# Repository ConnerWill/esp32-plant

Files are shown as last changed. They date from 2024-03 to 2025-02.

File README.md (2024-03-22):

# ESP32 Plant Monitoring / Watering System

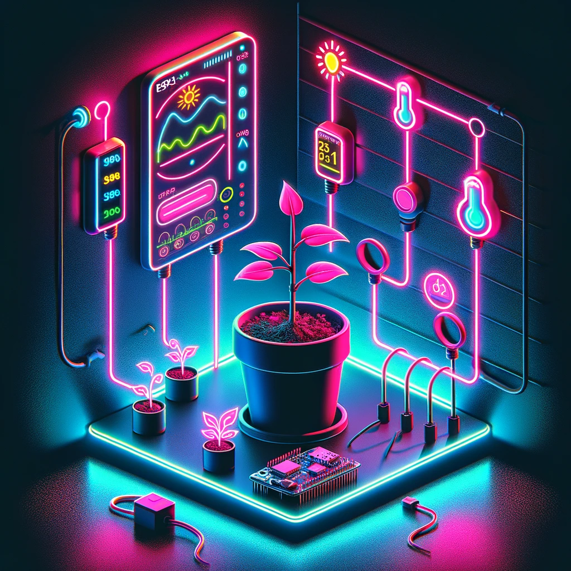
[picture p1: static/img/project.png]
ESP32 Plant Monitoring Project Image


---

# Overview

This project implements a monitoring system using an ESP32 microcontroller to measure and display temperature, humidity, and CO2 levels in real-time.

This is designed to be used to monitor the environment when growing plants

---

# Shopping List

Here is a list of parts used in this project

> *Amazon links are non-affiliate*

| NAME | PRICE | COUNT | DESCRIPTION | LINK | NOTE |
|---|---|---|---|---|---|
| ESP32 | $5 | 1 | Microcontroller | https://www.amazon.com/ESP-WROOM-31-Development-Microcontroller-Integrated-Compatible/dp/B08D5ZD528 | |
| DHT22 | $7 | 1 | Temp/Humidity Sensor | https://www.amazon.com/gp/product/B0795F19W6 | |
| MQ-135 | $3 | 1 | CO2 Sensor | https://www.amazon.com/Ximimark-Quality-Hazardous-Detection-Arduino/dp/B07L73VTTY | |
| 1K Ω Resistor  | $0.25 | 1 | 1K Ohm Resistor | https://www.amazon.com/California-JOS-Carbon-Resistor-Tolerance/dp/B0BR66ZN6B | MQ-135 analog pin |
| 10K Ω Resistor | $0.25 | 0/1 | 10K Ohm Resistor | https://www.amazon.com/California-JOS-Carbon-Resistor-Tolerance/dp/B0BR67DJHM | Most DHT22 sensor modules have a built-in resistor |
| Wire/Breadboard| $1 | 1 | Jumper wire or breadboard | https://www.amazon.com/DEYUE-breadboard-Set-Prototype-Board/dp/B07LFD4LT6 | Optional depending on setup |

<!--
| TLC555         | $3    | 1     | Capacitive soil moisture sensor | https://www.amazon.com/dp/B0C5STDNSX                                                                |                                                    |
| SSD1306        | $6    | 1     | 0.96" 128x64 OLED         | https://www.amazon.com/HiLetgo-Serial-128X64-Display-Color/dp/B06XRBTBTB                            | Optional if you want a screen display              |
| ENS160       | $5    | 0/1   | CO2 Sensor           | https://www.amazon.com/HiLetgo-Dioxide-Temperature-Humidity-Monitoring/dp/B0CDWYFSGH                |
| SGP30        | $5    | 0/1   | CO2 Sensor           | https://www.makerfabs.com/sgp30-air-quality-sensor-breakout.html                                    |
-->

> *Lower prices can be found if you shop around*

---

# Setup

Once you have all the required parts in hand, you can start wiring

## Circuit Schematic

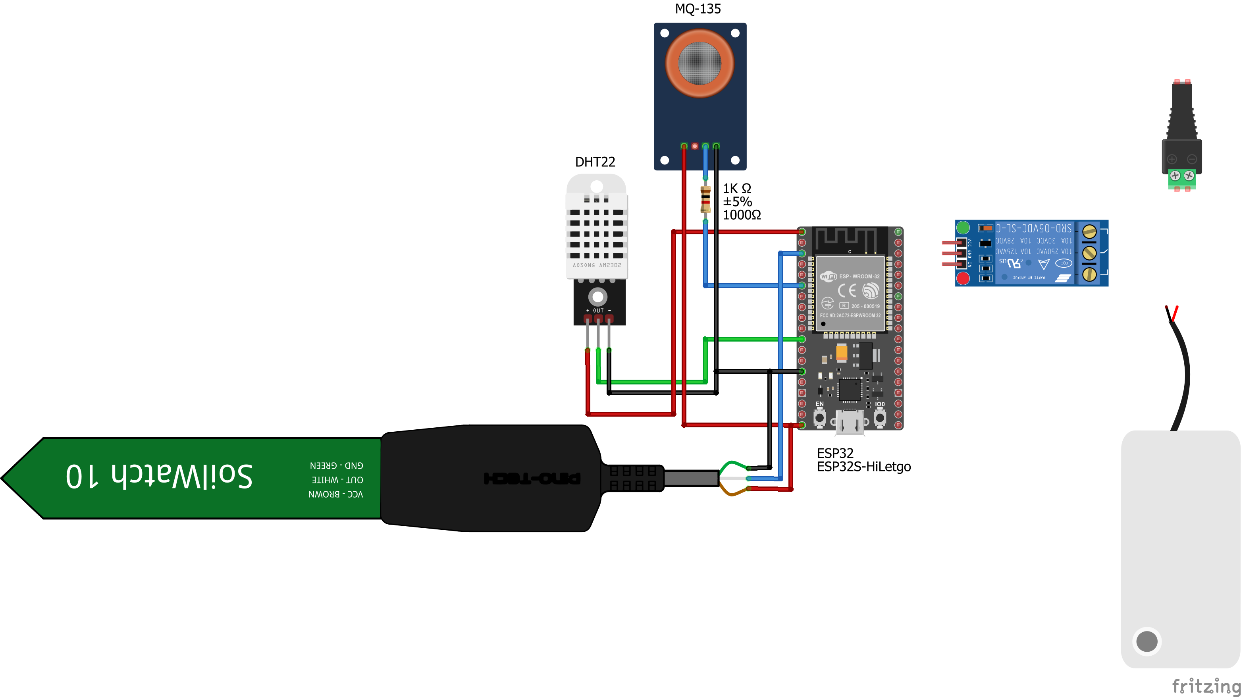
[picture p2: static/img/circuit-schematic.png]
ESP32 Plant Monitoring Circuit Schematic Image


| ESP32 Pin | Destination | Type | Power Requirements (Volts) | ESP32 VCC Pin | ESP32 GND Pin |
|---|---|---|---|---|---|
| 27 | DHT22 | Digital | 3-5 | 3.3V | GND |
| 35 | CO2 Sensor  | Analog  | 5 | 5V | GND |

> *Feel free to change the pins used on the ESP32, just note, if you change the pins, you will need to update the values in the code.*

## Configuration

You will need to define values to suite your needs. Variables are defined in [`./src/main/config.h`](/src/main/config.h)

### WiFI Configuration

Here is a list of WiFi variables that **must** be defined and their descriptions...

`WIFI_SSID`
: WiFi SSID (network/WiFi name)

`WIFI_PASSWORD`
: WiFi password

`WIFI_HOSTNAME`
: Hostname of ESP32 to set

### Other Configuration

Other variables in [`config.h`](/src/main/config.h) can be changed to suite your needs

## Uploading

I use Arduino IDE to upload the code to the board. I had to install additional drivers ***[(Download)](https://www.silabs.com/documents/public/software/CP210x_Universal_Windows_Driver.zip)*** to get connected to my board.

I installed the ESP32 boards and selected ESP32dev board.

---

# 3D Print

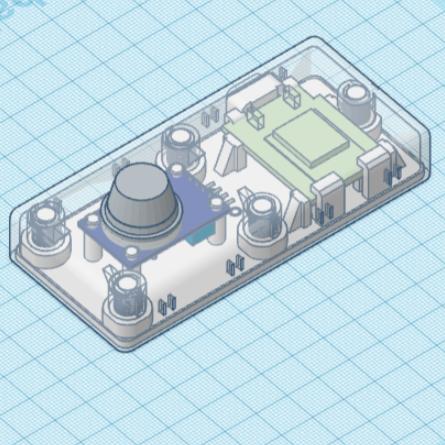
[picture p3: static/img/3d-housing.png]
ESP32 Plant Monitoring Housing Image


The housing to hold the ESP32 and sensors can be 3D printed.

The 3D model files are located under the [3D-models](/3D-models) directory.

## DHT22 Case

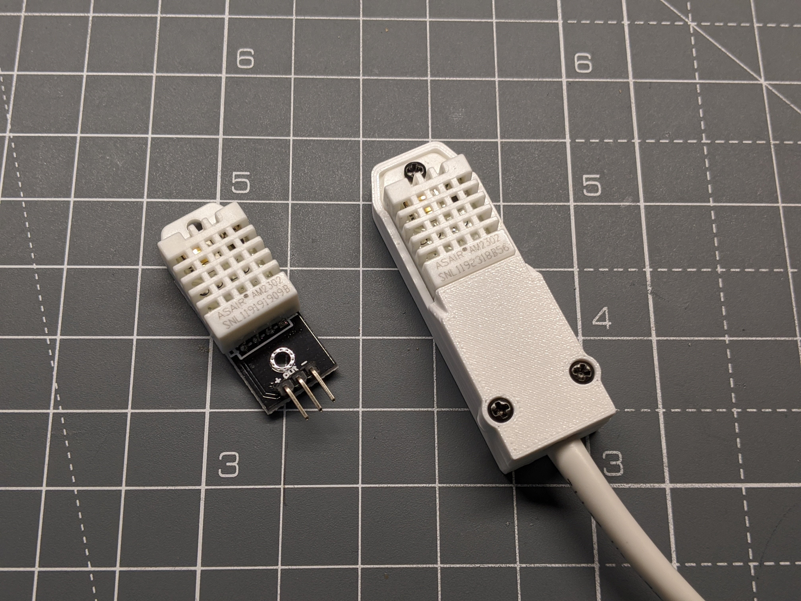
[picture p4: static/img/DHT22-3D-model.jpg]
DHT22 3D Printed Case


[Over-engineered DHT22 / AM2302 Board Case](https://www.thingiverse.com/thing:4521313)
: (Credit [SciMonster](https://www.thingiverse.com/SciMonster))

## MQ-135 Case

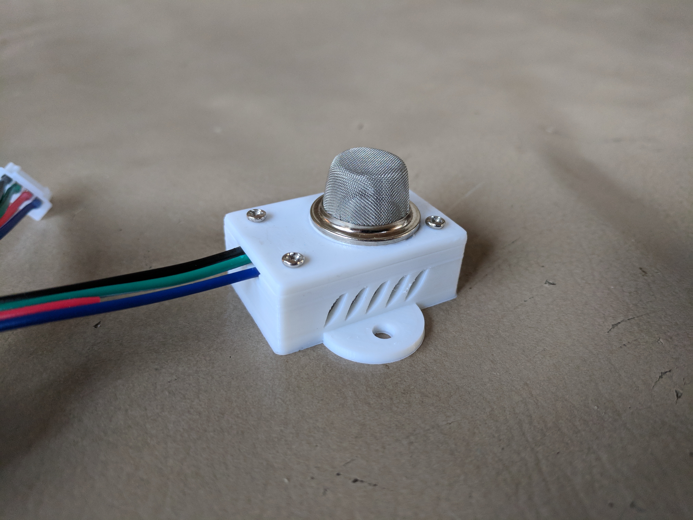
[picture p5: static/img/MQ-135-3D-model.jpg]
MQ-135 3D Printed Case


[MQ-2 Sensor Case](https://www.thingiverse.com/thing:2893581)
: (Credit [RJGII](https://www.thingiverse.com/RJGII))

---

# TODO

* Add wiring/setup instructions
* Add 3D models
* Replace images
* Improve code
* Add plotting

---

# Links

* https://microcontrollerslab.com/esp32-dht11-dht22-web-server
* https://blog.asksensors.com/air-quality-sensor-mq135-cloud-mqtt
* https://maker.pro/everything-esp/projects/how-to-control-a-relay-module-with-esp32
* https://www.thingiverse.com/thing:4521313
* https://www.thingiverse.com/thing:2893581

---

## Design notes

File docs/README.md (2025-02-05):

# ESP32 Plant Monitoring System

<div align="center">

ESP32 Plant Monitoring Project Image





</div>

---

## Table of Contents

<!--toc:start-->
- [ESP32 Plant Monitoring System](#esp32-plant-monitoring-system)
  - [Table of Contents](#table-of-contents)
  - [Overview](#overview)
  - [Shopping List](#shopping-list)
  - [Setup](#setup)
    - [Circuit Schematic](#circuit-schematic)
    - [ESP32 Pinout](#esp32-pinout)
      - [30 Pin](#30-pin)
      - [38 Pin](#38-pin)
    - [Configuration](#configuration)
      - [WiFI Configuration](#wifi-configuration)
      - [Other Configuration](#other-configuration)
    - [Libraries](#libraries)
      - [External Libraries](#external-libraries)
    - [Uploading](#uploading)
  - [Images](#images)
  - [3D Print](#3d-print)
  - [TODO](#todo)
  - [Links](#links)
<!--toc:end-->

---

## Overview

This project implements a monitoring system using an ESP32 microcontroller to
measure and display temperature, humidity, and CO2 levels in real-time.

This is designed to be used to monitor the environment when growing plants

---

## Shopping List

Here is a list of parts used in this project

> [!NOTE]
> *Amazon links are non-affiliate*

| NAME | PRICE | COUNT | DESCRIPTION | LINK | NOTE |
|---|---|---|---|---|---|
| ESP32 | $5 | 1 | Microcontroller | [Amazon](https://www.amazon.com/ESP-WROOM-31-Development-Microcontroller-Integrated-Compatible/dp/B08D5ZD528) | [USB-C ESP32 Amazon](https://www.amazon.com/dp/B0CR5Y2JVD) |
| DHT22 | $3 | 1 | Temp/Humidity Sensor | [Amazon](https://www.amazon.com/dp/B0CPHQC9SF) | |
| MQ-135 | $3 | 1 | CO2 Sensor | [Amazon](https://www.amazon.com/Ximimark-Quality-Hazardous-Detection-Arduino/dp/B07L73VTTY) | |
| OLED Display | $3 | 1 | 0.96" OLED Display 128x64 SSD1306 | [Amazon](https://www.amazon.com/Hosyond-Display-Self-Luminous-Compatible-Raspberry/dp/B09C5K91H7) | |
| Kasa Smart Plug  | $7.50 | 2 | TP-Link Kasa Smart Plug HS103 | [Amazon](https://www.amazon.com/dp/B07RCNB2L3) | Intake and exhaust fans smart plugs |
| Rocker Switch | $0.60 | 2 | Rocker Switch On/Off 2 Pin | [Amazon](https://www.amazon.com/dp/B0CVTRKJTV) | |
| 1K Ω Resistor | $0.25 | 1 | 1K Ohm Resistor | [Amazon](https://www.amazon.com/California-JOS-Carbon-Resistor-Tolerance/dp/B0BR66ZN6B) | MQ-135 analog pin |
| 10K Ω Resistor | $0.25 | 0/1/2 | 10K Ohm Resistor | [Amazon](https://www.amazon.com/California-JOS-Carbon-Resistor-Tolerance/dp/B0BR67DJHM) | Most DHT22 sensor modules have a built-in resistor |
| Wire/Breadboard  | $1 | 0/1 | Jumper wire or breadboard | [Amazon](https://www.amazon.com/DEYUE-breadboard-Set-Prototype-Board/dp/B07LFD4LT6) | Optional depending on setup |
| Breakout Board | $4 | 0/1 | ESP32 Breakout Board GPIO | [Amazon](https://www.amazon.com/dp/B0BNQ8V65G) | Optional depending on setup |
| Buck Converter | $1 | 0/1 | LM2596 DC-DC Buck Converter Step Down | [Amazon](https://www.amazon.com/dp/B07VVXF7YX) | Optional depending on setup |
| Barrel Jack | $1 | 0/1 | Female DC Barrel Jack Panel Adapter | [Amazon](https://www.amazon.com/Threaded-Adapter-Connector-Dustproof-lkelyonewy/dp/B091PS6XQ4) | Optional depending on setup |
| 1N5819 Diode | $0.1 | 0/1 | 1N5819 Schottky Diode | [Amazon](https://www.amazon.com/ALLECIN-1N5819-Schottky-Rectifier-Switching/dp/B0CKSHSWPS) | Optional depending on setup |
| 1000µF Capacitor | $0.4 | 0/1 | 1000uF 10V 8x12mm Capacitor | [Amazon](https://www.amazon.com/ALLECIN-Electrolytic-Capacitor-0-32x0-47in-Capacitors/dp/B0CMQCC5D3) | Optional depending on setup |

> [!TIP]
> *Lower prices can be found if you shop around*

---

## Setup

Once you have all the required parts in hand, you can start wiring

### Circuit Schematic

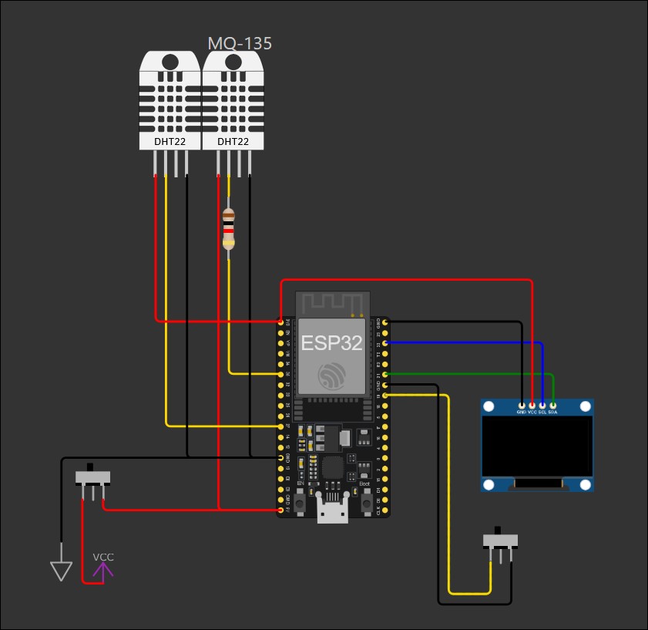
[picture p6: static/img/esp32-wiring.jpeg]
ESP32 Plant Wiring (https://wokwi.com/projects/421434545777653761)


ESP32 Plant Monitoring Circuit Schematic Image

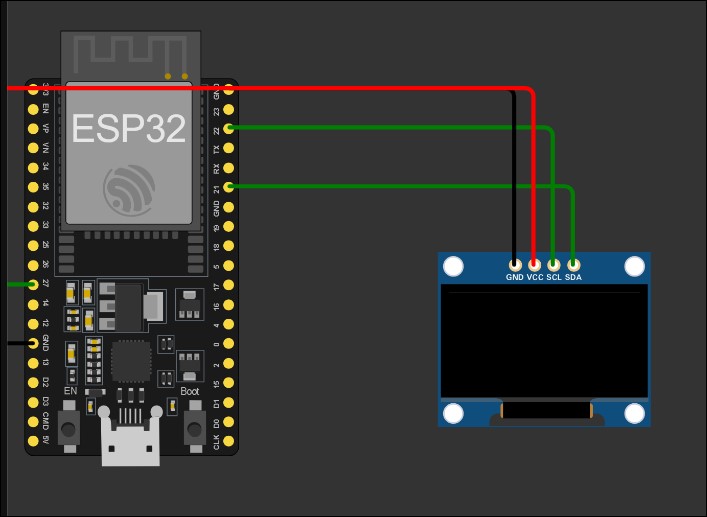
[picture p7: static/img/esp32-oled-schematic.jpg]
ESP32 OLED Circuit Schematic Image


| ESP32 Pin | Destination | Type | Power Requirements (Volts) | ESP32 VCC Pin | ESP32 GND Pin |
|---|---|---|---|---|---|
| 27 | DHT22 | Digital | 3.3 - 5 | 3.3V | GND |
| 35 | CO2 Sensor | Analog  | 5 | 5V | GND |
| 21 | OLED SCL | SCL | 3.3 | 3.3V | GND |
| 22 | OLED SDA | SDA | 3.3 | 3.3V | GND |
| 19 | Rocker Switch | GPIO | | | GND |

> [!NOTE]
> *Feel free to change the pins used on the ESP32, just note, if you change the pins, you will need to update the values in the code.*

### ESP32 Pinout

#### 30 Pin

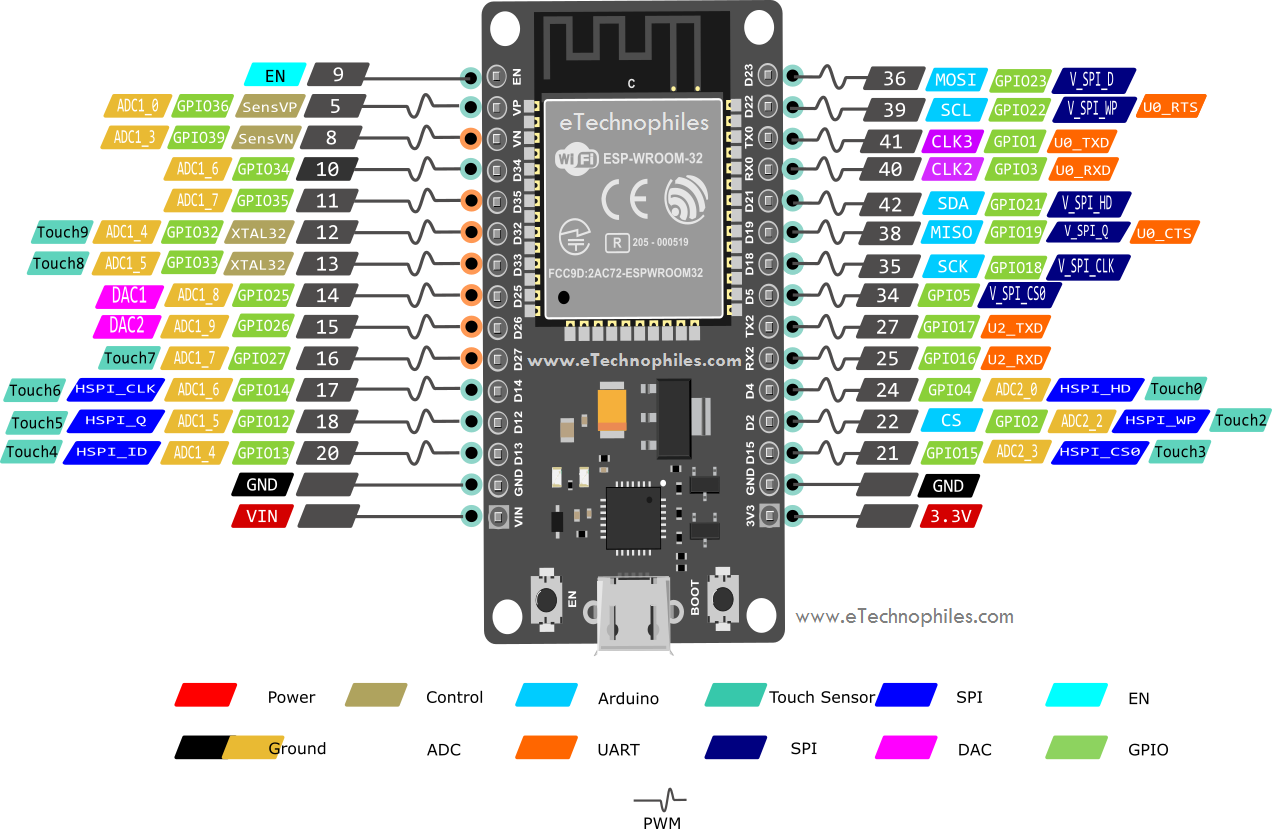
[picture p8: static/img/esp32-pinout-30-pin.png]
ESP32 30 pin Pinout Image


#### 38 Pin

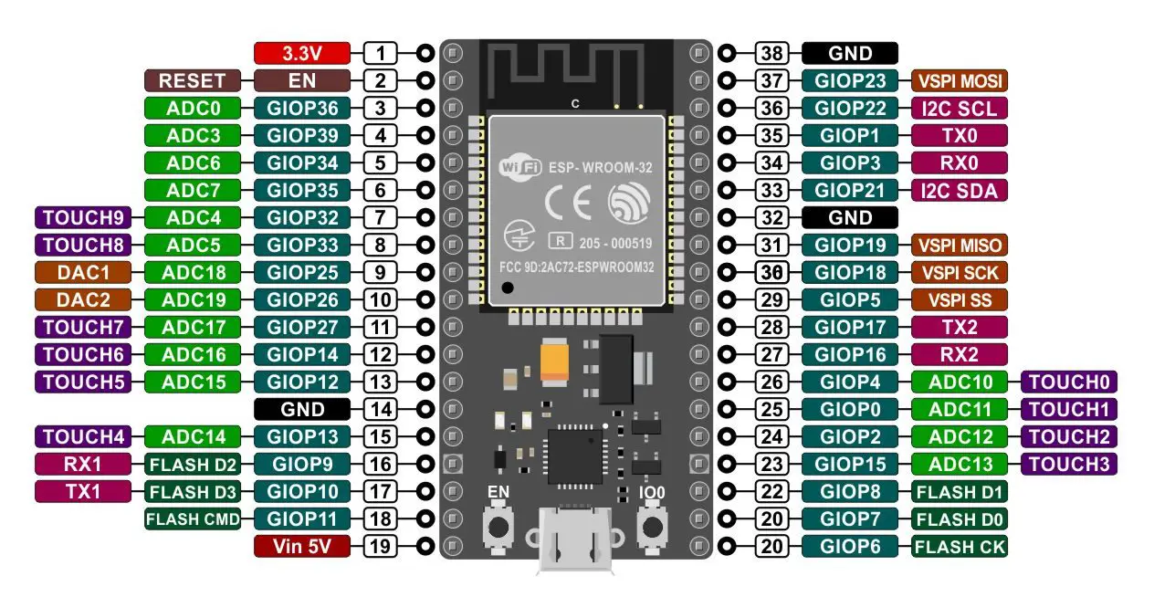
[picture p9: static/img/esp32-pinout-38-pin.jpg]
ESP32 38 pin Pinout Image


### Configuration

You will need to define values to suite your needs. Variables are defined in [`config.h`](/src/main/config.h)

#### WiFI Configuration

Here is a list of WiFi variables that **must** be defined and their descriptions...

`WIFI_SSID`
: WiFi SSID (network/WiFi name)

`WIFI_PASSWORD`
: WiFi password

`WIFI_HOSTNAME`
: Hostname of ESP32 to set

#### Other Configuration

Other variables in the code can be changed to suite your needs

### Libraries

You will need to install additional libraries.

In Arduino IDE, go to library manager and search and install the
required libraries listed in the `DEPENDENCIES` section in [`main.ino`](/src/main/main.ino)

#### External Libraries

- [KasaSmartPlug Github](https://github.com/ConnerWill/KasaSmartPlug)

---

### Uploading

I use Arduino IDE to upload the code to the board. I had to install additional drivers ***[(Download)](https://www.silabs.com/documents/public/software/CP210x_Universal_Windows_Driver.zip)*** to get connected to my board.

I installed the ESP32 boards and selected ESP32dev board.

---

## Images

<!--TODO: Add more images-->

| | |
|---|---|
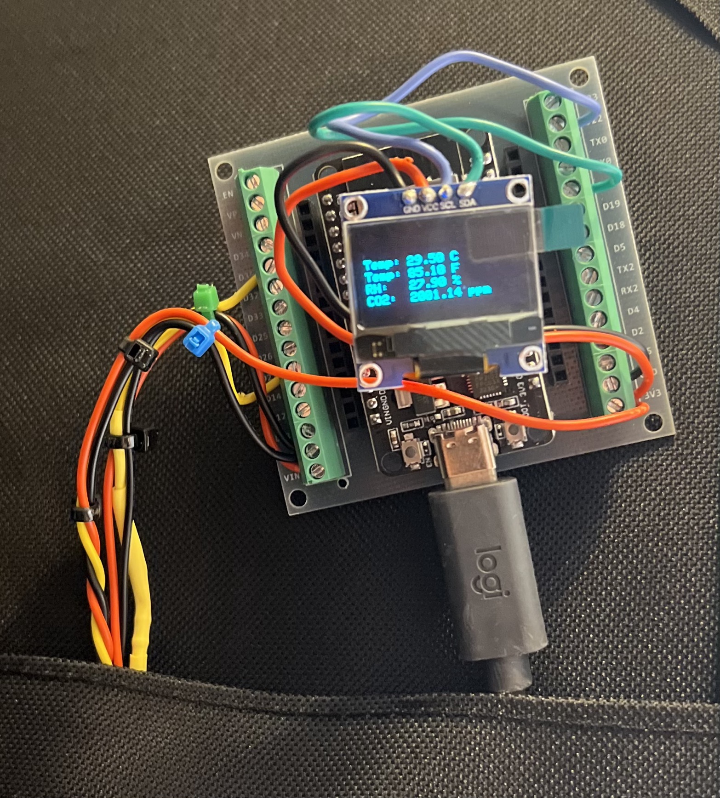
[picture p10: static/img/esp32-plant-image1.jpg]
ESP32 Plant Monitoring Project Image 1
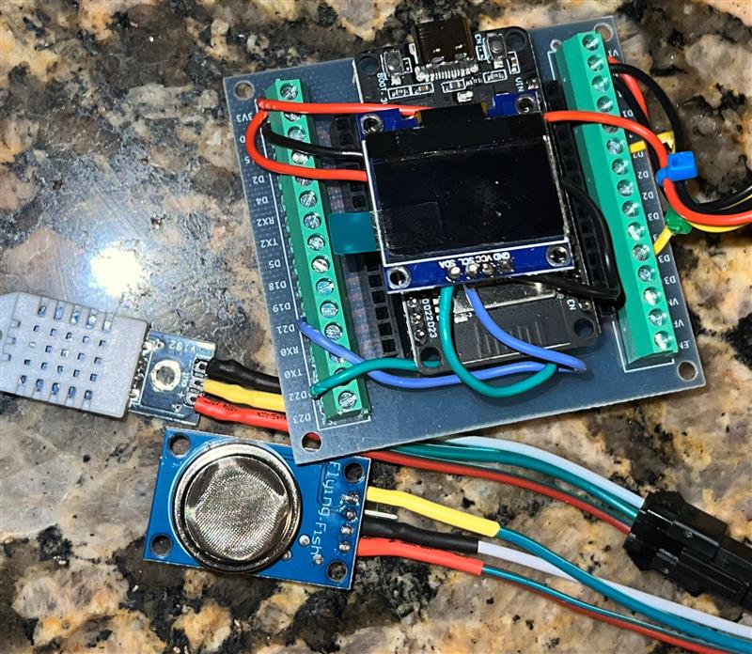
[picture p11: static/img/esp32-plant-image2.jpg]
ESP32 Plant Monitoring Project Image 2
|  |  |
| ESP32 Plant Monitoring Project Image | ESP32 Plant Monitoring Project Image |

---

## 3D Print

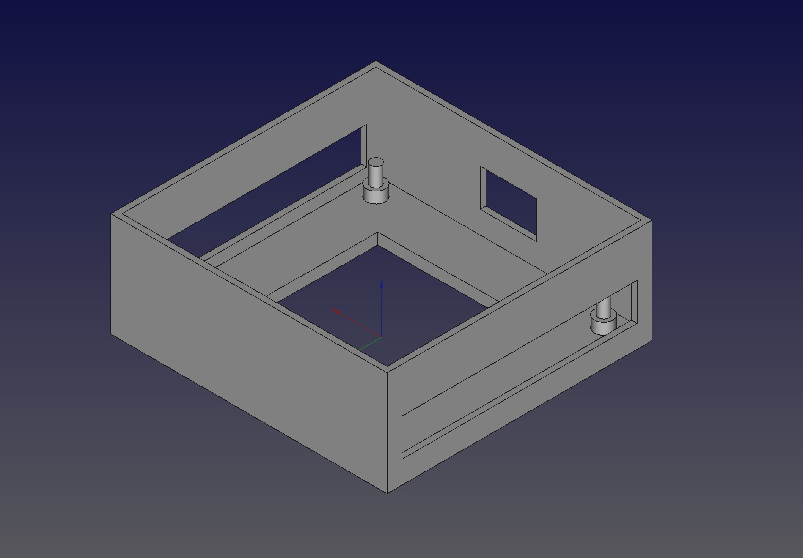
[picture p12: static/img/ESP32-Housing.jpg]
ESP32 Plant Monitoring Housing 3D Image


The housing to hold the ESP32 can be 3D printed.

The 3D model files are located under the [3D-models](/3D-models) directory.

| Name | Image | Link | Author |
|---|---|---|---|
| ESP32-Plant Case | ESP32-Plant Case Image | [ESP32-Plant Case Case](/3D-models/ESP32-housing/) | [ConnerWill](https://github.com/ConnerWill) |
| DHT22 Case | DHT22 Case Image | [Over-engineered DHT22 / AM2302 Board Case](https://www.thingiverse.com/thing:4521313) | [SciMonster](https://www.thingiverse.com/SciMonster) |
| MQ-135 Case | MQ-135 Case Image | [MQ-2 Sensor Case](https://www.thingiverse.com/thing:2893581) | [RJGII](https://www.thingiverse.com/RJGII) |

---

## TODO

- [ ] Improve wiring/setup instructions
- [ ] Finish 3D models
- [ ] Add finished product images
- [ ] Improve code

---

## Links

- [microcontrollerslab.com/esp32-dht11-dht22-web-server](https://microcontrollerslab.com/esp32-dht11-dht22-web-server)
- [blog.asksensors.com/air-quality-sensor-mq135-cloud-mqtt](https://blog.asksensors.com/air-quality-sensor-mq135-cloud-mqtt)
- [maker.pro/everything-esp/projects/how-to-control-a-relay-module-with-esp32](https://maker.pro/everything-esp/projects/how-to-control-a-relay-module-with-esp32)
- [thingiverse.com/thing:4521313](https://www.thingiverse.com/thing:4521313)
- [thingiverse.com/thing:2893581](https://www.thingiverse.com/thing:2893581)
- [javl.github.io/image2cpp](https://javl.github.io/image2cpp)
- [github.com/ConnerWill/KasaSmartPlug](https://github.com/ConnerWill/KasaSmartPlug)

---

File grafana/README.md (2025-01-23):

# ESP32 Sensor Data Collector and Grafana Dashboard

This project collects sensor data (temperature, humidity, CO2) from an ESP32 device,
stores the data in InfluxDB, and visualizes it using Grafana.

The entire setup runs in Docker containers, including a Python script that
fetches sensor data, InfluxDB for storing the data, and Grafana for visualization.

## Project Structure

```console
.
├── docker-compose.yml              # Docker Compose file to bring up all services
├── README.md                       # Documentation
├── grafana-provisioning            # Directory for grafana configuration
│   └── datasources                 # Directory for custom grafana configurations
│       └── influxdb-datasource.yml # InfluxDB grafana datasource
├── sensor_data_collector           # Directory for Python script and requirements
│   ├── Dockerfile                  # Dockerfile to build the Python script container
│   ├── fetch_data.py               # Python script to fetch data from ESP32 and store in InfluxDB
│   └── requirements.txt            # Python dependencies
└── setup.sh                        # Setup script to install and configure docker
```

## Prerequisites

- Docker and Docker Compose installed on your system.
- ESP32 device providing data via HTTP.

## Setup

### Step 1: Build and Start Containers

Run the following command to start the containers:

```bash
docker-compose up --build
```

This will:

- Build the Python script container (python-script).
- Start the InfluxDB container to store the sensor data.
- Start the Grafana container for data visualization.

### Step 2: Configure Environment Variables

You can configure the following environment variables, which will be used by the Python script:

- `ESP32_IP`: IP address of the ESP32 device *(defaults to [`http://192.168.0.30`](http://192.168.0.30))*.
- `INFLUXDB_HOST`: Hostname of the InfluxDB instance *(defaults to `influxdb`)*.
- `INFLUXDB_PORT`: Port for InfluxDB *(defaults to `8086`)*.
- `INFLUXDB_DB`: Name of the database to store data *(defaults to `esp32_data`)*.
- `POLL_INTERVAL`: Interval in seconds for polling the ESP32 device *(defaults to `2`)*.

These environment variables can be set directly in your system
or in the Docker container using .env files or
Docker's environment variable configuration.

```bash
ESP32_IP=http://192.168.0.30
INFLUXDB_HOST=influxdb
INFLUXDB_DB=esp32_data
POLL_INTERVAL=2
```

### Step 3: Grafana Configuration

Once the containers are up and running, you can access Grafana at `http://localhost:3000`:

- Username: `admin`
- Password: `admin`

In Grafana, you'll need to add InfluxDB as a data source:

1. Go to Configuration > Data Sources.
2. Choose InfluxDB.
3. Set the URL to `http://influxdb:8086` *(or the relevant InfluxDB service URL)*.
4. Set the database name to esp32_data *(or the value you configured in the `INFLUXDB_DB` variable)*.
5. Save and test the connection.

### Step 4: Create Dashboards in Grafana

Once InfluxDB is configured in Grafana,
you can create dashboards to visualize the sensor data.
You'll be able to plot the temperature, humidity, and CO2 values over time.

## Docker Compose Configuration

The docker-compose.yml file defines three services:

- `influxdb`: The InfluxDB instance where sensor data is stored.
- `grafana`: The Grafana instance to visualize the data.
- `python-script`: The Python script that fetches data from the ESP32 and writes it to InfluxDB.

```yaml
version: '3.8'

services:
  influxdb:
    image: influxdb:1.8
    container_name: influxdb
    ports:
      - "8086:8086"
    volumes:
      - influxdb-data:/var/lib/influxdb
    environment:
      INFLUXDB_DB: esp32_data
      INFLUXDB_ADMIN_USER: admin
      INFLUXDB_ADMIN_PASSWORD: admin

  grafana:
    image: grafana/grafana:latest
    container_name: grafana
    ports:
      - "3000:3000"
    environment:
      - GF_SECURITY_ADMIN_USER=admin
      - GF_SECURITY_ADMIN_PASSWORD=admin
    depends_on:
      - influxdb
    volumes:
      - grafana-data:/var/lib/grafana

  python-script:
    build:
      context: ./sensor_data_collector
    container_name: sensor_data_collector
    depends_on:
      - influxdb

volumes:
  influxdb-data:
  grafana-data:
```

## Python Script

The Python script *(`fetch_data.py`)* fetches data from the ESP32 device
and writes it to InfluxDB.

It uses the requests library to pull data from the ESP32's IP address, and influxdb to store the data.

### Python Dependencies

The required Python dependencies are listed in requirements.txt:

```python
requests>=2.25.0
influxdb>=5.3.0
```

The `fetch_data.py` script handles the following:

- Fetching sensor data from the ESP32 using the HTTP GET request.
- Writing the fetched data (temperature, humidity, CO2) to InfluxDB.
- Configuring default values for environment variables if they are not provided.

### Dockerfile for Python Script

The Dockerfile builds the Python script container,
ensuring the required dependencies are installed.

```bash
FROM python:3.9-slim

# Set working directory
WORKDIR /app

# Copy requirements.txt into the container
COPY requirements.txt .

# Install dependencies from requirements.txt
RUN pip install --no-cache-dir -r requirements.txt

# Copy the Python script into the container
COPY fetch_data.py .

# Run the Python script
CMD ["python", "fetch_data.py"]
```

## Conclusion

This project provides an easy way to collect, store, and visualize sensor data
from an ESP32 device using InfluxDB and Grafana in Docker containers.
The Python script handles the data collection and storage, and Grafana provides an intuitive dashboard for data visualization.

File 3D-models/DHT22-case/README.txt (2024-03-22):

Over-engineered DHT22 / AM2302 Board Case by SciMonster on Thingiverse: https://www.thingiverse.com/thing:4521313

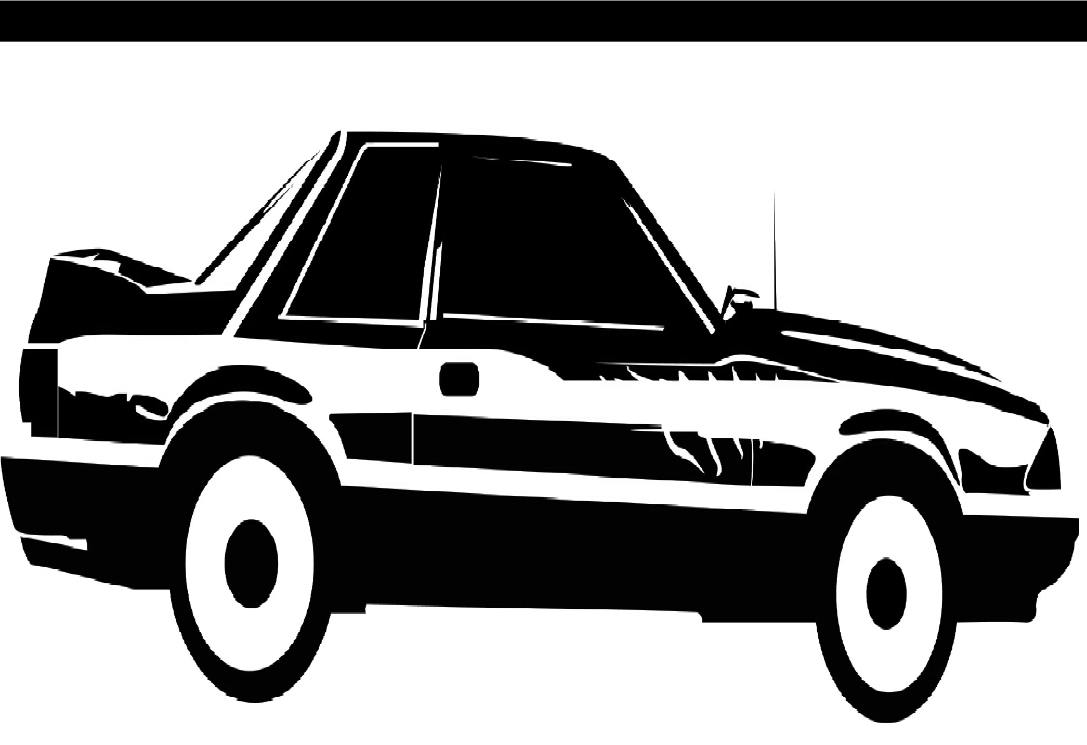
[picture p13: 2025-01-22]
static/img/mustang.png

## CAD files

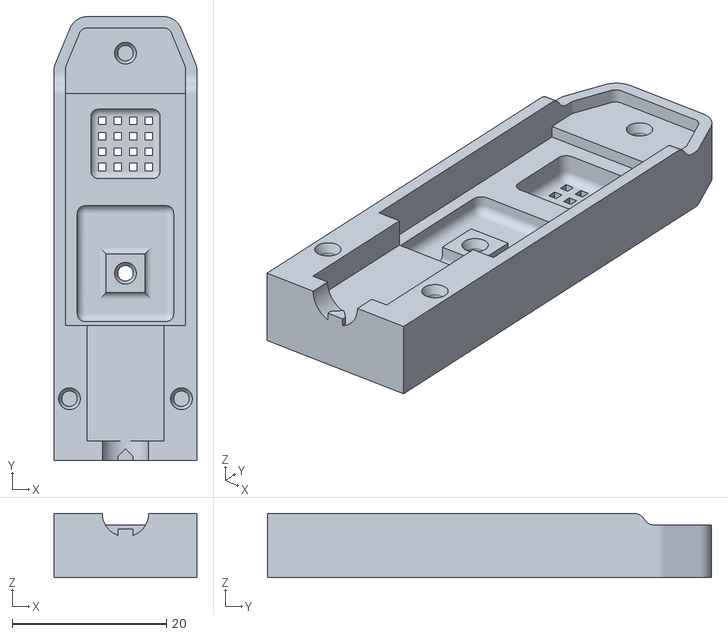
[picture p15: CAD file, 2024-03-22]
3D-models/DHT22-case/DHT22_bottom.stl
18.5 x 57.5 x 8.30

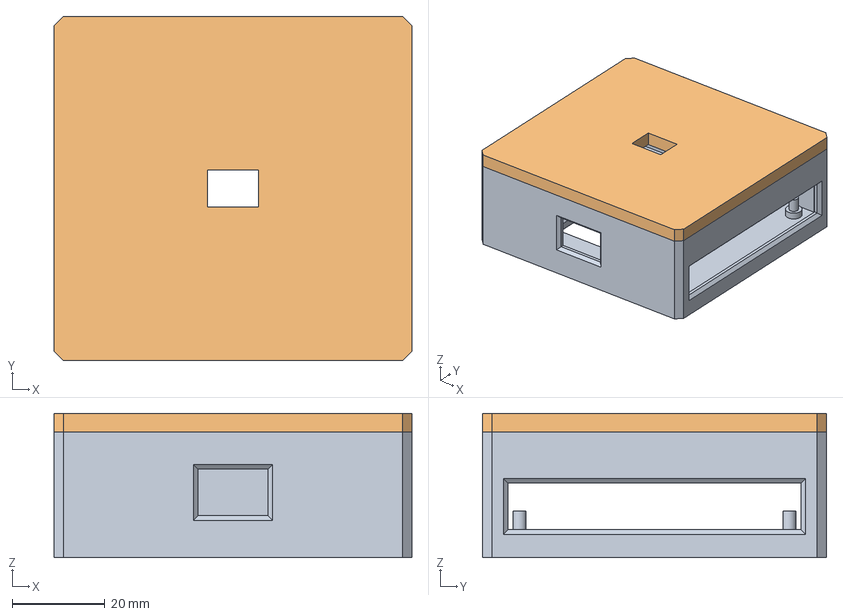
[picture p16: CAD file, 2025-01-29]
3D-models/ESP32-housing/ESP32-housing.FCStd
77.0 x 74.0 x 31.0 mm
ESP32-Housing
ESP32-Housing-Lid

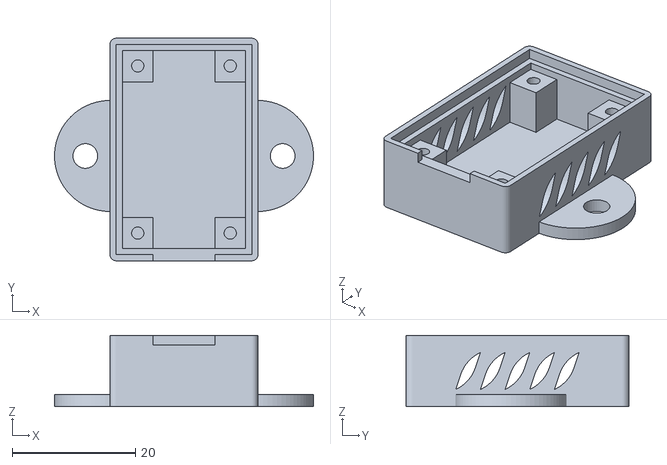
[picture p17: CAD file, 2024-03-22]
3D-models/MQ-135-case/MQ2-Bottom-02.stl
42.0 x 36.1 x 11.6

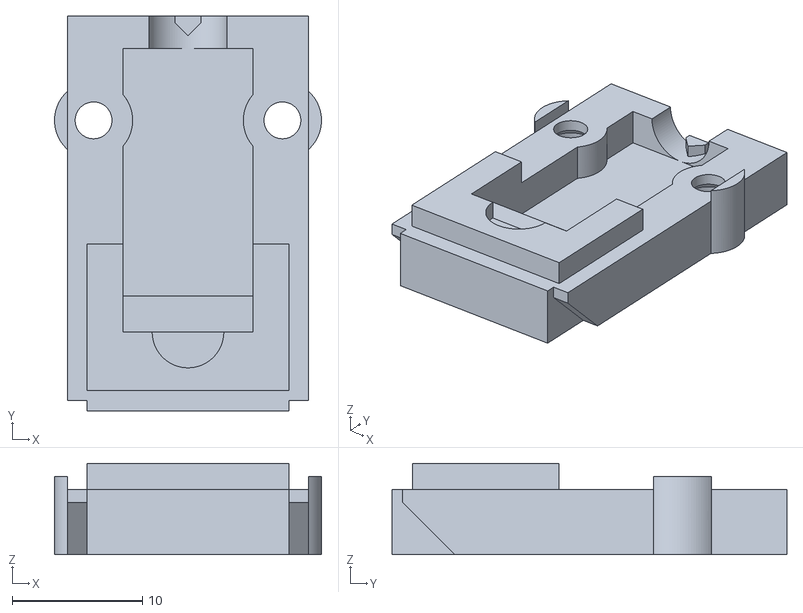
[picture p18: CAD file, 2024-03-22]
3D-models/DHT22-case/DHT22_top.stl
20.5 x 30.3 x 7.00

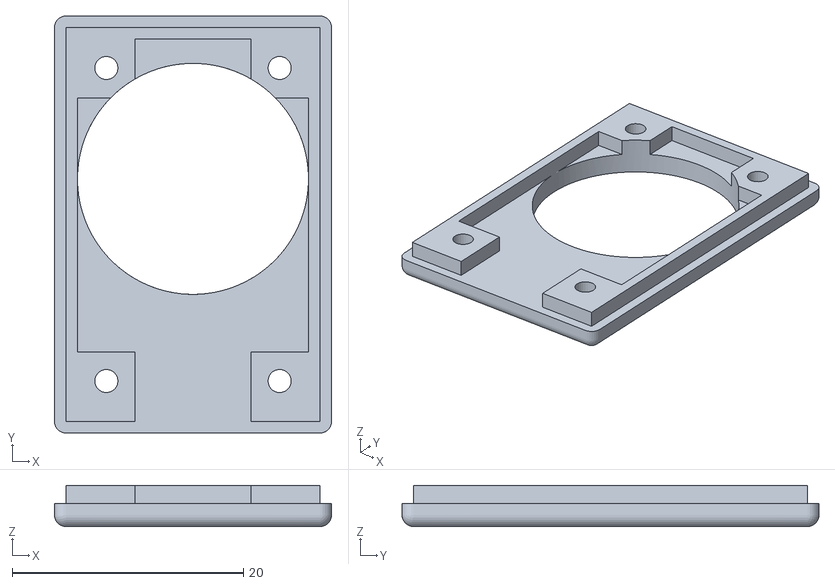
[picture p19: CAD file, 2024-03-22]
3D-models/MQ-135-case/MQ2-Top-02.stl
24.0 x 36.1 x 3.55

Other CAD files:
3D-models/ESP32-housing/ESP32-housing.3mf
3D-models/ESP32-housing/ESP32-housing.stl

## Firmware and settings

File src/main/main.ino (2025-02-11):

/*
 * File: ./main.ino
 */

// ============================================================================
// DEPENDENCIES -----------------------------------------------------------
// ============================================================================
#include "WiFi.h"
#include "ESPAsyncWebServer.h"
#include "DHTesp.h"
#include <ArduinoJson.h>
#include <Wire.h>
#include <Adafruit_GFX.h>
#include <Adafruit_SSD1306.h>
#include "KasaSmartPlug.h"     // KASA TP-link smart plug library: https://github.com/ConnerWill/KasaSmartPlug
#include "config.h"            // Include config header file
#include "bitmap.h"            // Include bitmap header file
// ============================================================================

// ============================================================================
// GLOBAL INSTANCES -----------------------------------------------------------
// ============================================================================
DHTesp dht;                                                       // DHT
Adafruit_SSD1306 display(SCREEN_WIDTH, SCREEN_HEIGHT, &Wire, -1); // Declaration for an SSD1306 display connected to I2C (SDA, SCL pins)
AsyncWebServer server(SERVER_PORT);                               // Define server on port
KASAUtil kasaUtil;                                                // Kasa utility object
KASASmartPlug *intakePlug = NULL;                                 // Smart plug pointers (Intake)
KASASmartPlug *exhaustPlug = NULL;                                // Smart plug pointers (Exhaust)
KASASmartPlug *humidifierPlug = NULL;                             // Smart plug pointers (Humidifier)
// ============================================================================

// ============================================================================
// FUNCTIONS ------------------------------------------------------------------
// ============================================================================
// -------------------------------------
// Sensor Functions
// -------------------------------------
// Function to get the CO2 measurement 
float readCO2() {
  constexpr float ReferenceVoltage  = 3.3;
  constexpr float MaxAdcValue       = 4095.0;
  constexpr float VoltageThreshold  = 0.4;
  constexpr float CalibrationFactor = 5000.0;
  constexpr float VoltageOffset     = 1.6;

  int adcVal = analogRead(CO2_PIN);                          // Read analog value from CO2 sensor
  float voltage = adcVal * (ReferenceVoltage / MaxAdcValue); // Calculate voltage based on ADC value

  // Calculate CO2 measurement based on voltage difference
  if (voltage == 0 || voltage < VoltageThreshold) {
    Serial.println(F("Error reading CO2"));
    return 0.0; // Return 0 for sensor errors or pre-heating
  } else {
    float voltageDifference = voltage - VoltageThreshold;
    return (voltageDifference * CalibrationFactor) / VoltageOffset;
  }
}

// Function to read temperature
float readTemperature() {
  float temperature = dht.getTemperature();
  if (isnan(temperature)) {
      Serial.printf("Error reading temperature: %s\n", dht.getStatusString());
      return 0.0;
  }
  return temperature;
}

// Function to read humidity
float readHumidity() {
  float humidity = dht.getHumidity();
  if (isnan(humidity)) {
      Serial.printf("Error reading humidity: %s\n", dht.getStatusString());
      return 0.0;
  }
  return humidity;
}

// Function to convert Celsius to Fahrenheit
float celsiusToFahrenheit(float celsius) {
  float fahrenheit = (celsius * 9.0 / 5.0) + 32.0;
  return fahrenheit;
}


// -------------------------------------
// Switch Functions
// -------------------------------------
// Function to read and update the state of the FLOWER variable based on the rocker switch
void updateFlowerState() {
  int rockerState = digitalRead(ROCKER_SWITCH_PIN);
  FLOWER = (rockerState == LOW); // Assuming LOW means ON
}


// -------------------------------------
// KASA TP-Link Smart Plug Functions
// -------------------------------------
// Function to initialize smart plugs
void initSmartPlugs() {
  // Check if we are connected to WiFi
  if (WiFi.status() != WL_CONNECTED) {
      Serial.println("Not connected to WiFi. Skipping smart plug setup");
      return;
  }

  int found = kasaUtil.ScanDevices();
  Serial.printf("Found %d Kasa devices\n", found);

  display.clearDisplay();
  display.setCursor(0, 0);
  display.print("KASA devices found: ");
  display.println(found);
  display.display();
  delay(500);

  // Loop through found devices and match aliases
  for (int i = 0; i < found; i++) {
    KASASmartPlug *plug = kasaUtil.GetSmartPlugByIndex(i);
    if (plug == NULL) continue;

    Serial.printf("Found Plug: %s (IP: %s, State: %d)\n", plug->alias, plug->ip_address, plug->state);

    display.clearDisplay();
    display.setCursor(0, 0);
    display.print("KASA Smart Plugs");
    display.setCursor(0, 16);
    display.print("Alias: ");
    display.println(plug->alias);
    display.print("IP   : ");
    display.println(plug->ip_address);
    display.print("State   : ");
    display.println(plug->state);
    display.display();
    delay(1000);

    // Match plugs by their aliases
    if (strcmp(plug->alias, intakePlugAlias) == 0) {
      intakePlug = plug;
      Serial.println("Intake plug initialized.");
    } else if (strcmp(plug->alias, exhaustPlugAlias) == 0) {
      exhaustPlug = plug;
      Serial.println("Exhaust plug initialized.");
    } else if (strcmp(plug->alias, humidifierPlugAlias) == 0) {
      humidifierPlug = plug;
      Serial.println("Humidifier plug initialized.");
    }
  }

  // Check if plugs were found
  //TODO: Could clean this up
  if (intakePlug == NULL) {
    Serial.println("Error: Intake plug not found!");

    display.clearDisplay();
    display.setCursor(0, 0);
    display.print("ERROR: Intake plug not found");
    display.display();
    delay(1000);
  }
  if (exhaustPlug == NULL) {
    Serial.println("Error: Exhaust plug not found!");

    display.clearDisplay();
    display.setCursor(0, 0);
    display.print("ERROR: Exhaust plug not found");
    display.display();
    delay(1000);
  }
  if (humidifierPlug == NULL) {
    Serial.println("Error: Humidifier plug not found!");

    display.clearDisplay();
    display.setCursor(0, 0);
    display.print("ERROR: Humidifier plug not found");
    display.display();
    delay(1000);
  }
}

// Function to turn a plug on or off
void setPlugState(KASASmartPlug* plug, bool state) {
  // Setting variable for printing. otherwise dont need this
  //KASASmartPlug *plugAlias = kasaUtil.GetSmartPlug(plug->alias);

  // Check if we are connected to WiFi
  if (WiFi.status() != WL_CONNECTED) {
      Serial.println("Not connected to WiFi. Cannot set plug state");
      return;
  }

  if (plug == NULL) {
    //Serial.printf("Error: Could not find plug with alias '%s'\n", plugAlias);
    return;
  }

  if (state) {
    //Serial.printf("Turning ON plug: %s\n", plugAlias);
    plug->SetRelayState(1); // Turn on
  } else {
    //Serial.printf("Turning OFF plug: %s\n", plugAlias);
    plug->SetRelayState(0); // Turn off
  }
}

// Function to control fans based on temperature
void handleTemperature(float temperatureF, float desiredTemp, const char* mode) {
  if (temperatureF > desiredTemp + TEMP_HYSTERESIS) {                                                // Temp too high
    Serial.printf("Temperature too high in %s mode! Turning on intake and exhaust fans...\n", mode); //
    setPlugState(exhaustPlug, true);                                                                 // Turn on exhaust fan
    setPlugState(intakePlug, true);                                                                  // Turn on intake fan

  } else if (temperatureF < desiredTemp - TEMP_HYSTERESIS) {                                         // Temp too low
    Serial.printf("Temperature too low in %s mode! Turning off intake and exhaust fans...\n", mode); //
    setPlugState(exhaustPlug, false);                                                                // Turn off exhaust fan
    setPlugState(intakePlug, false);                                                                 // Turn off intake fan

  } else {                                                                                           // Temperature within range
    setPlugState(exhaustPlug, false);                                                                // Turn off exhaust fan to save energy
    setPlugState(intakePlug, false);                                                                 // Turn off intake fan to save energy
  }
}

// Function to control humidifier based on humidity
void handleHumidity(float humidity, float desiredHumidity, const char* mode) {
  if (humidity > desiredHumidity + HUMIDITY_HYSTERESIS) {                                                       // Humidity too high
    Serial.printf("Humidity too high in %s mode! Turning off humidifier... Turning on exhaust fan...\n", mode); //
    setPlugState(humidifierPlug, false);                                                                        // Turn off humidifier
    setPlugState(exhaustPlug, true);                                                                            // Turn on exhaust fan

  } else if (humidity < desiredHumidity - HUMIDITY_HYSTERESIS) {                                                // Humidity too low
    Serial.printf("Humidity too low in %s mode! Turning on humidifier...\n", mode);                             //
    setPlugState(humidifierPlug, true);                                                                         // Turn on humidifier

  } else {                                                                                                      // Humidity within range
    setPlugState(humidifierPlug, false);                                                                        // Turn off humidifier to save energy
  }
}

// -------------------------------------
// WIFI Functions
// -------------------------------------
// Function to connect to Wi-Fi
void connectToWiFi() {
  Serial.println(F("Setting up Wi-Fi..."));

  WiFi.mode(WIFI_STA); // Station mode only

  if (!WiFi.setHostname(WIFI_HOSTNAME)) {
    Serial.printf("Error: Failed to set Wi-Fi hostname: %s\n", WIFI_HOSTNAME);
  }

  display.clearDisplay();
  display.setCursor(0, 0);
  display.println("Connecting to WiFi");
  display.setCursor(0, 16);
  display.println(WIFI_SSID);
  display.display();
  delay(100);

  WiFi.begin(WIFI_SSID, WIFI_PASSWORD);
  Serial.printf("Connecting to WiFi: %s\n", WIFI_SSID);

  // Record the start time of the connection attempt
  unsigned long startAttemptTime = millis();
  while (WiFi.status() != WL_CONNECTED) {
    if (millis() - startAttemptTime >= WIFI_TIMEOUT_TIME) { // Timeout after X seconds
      Serial.printf("Failed to connect to WiFi: %s\n", WIFI_SSID);

      // TODO: Values are not updating when wifi is disconnected
      display.clearDisplay();
      display.setCursor(0, 0);
      display.println("Failed to connect to WiFi!");
      display.setCursor(0, 16);
      display.println(WIFI_SSID);
      display.display();
      delay(SCREEN_STARTUP_DISPLAY_TIME);
      display.clearDisplay();

      return;
    }
    delay(1000);
    Serial.print(".");

    // Connecting loading bar
    display.print("_");
    display.display();
  }

  Serial.println(F("Wi-Fi Connected"));

  // Display IP info
  showIPInfo();
  delay(SCREEN_STARTUP_DISPLAY_TIME);
}

// -------------------------------------
// OLED Functions
// -------------------------------------
// Function to initialize OLED
void initOLED() {
  if (!display.begin(SSD1306_SWITCHCAPVCC, SCREEN_ADDRESS)) {
    Serial.println(F("Failed to start SSD1306 OLED"));
    while (1);
  }

  // Show start text if SHOW_STARTUP is true
  if (SHOW_STARTUP) {
    showStart();
  }
  // Display bitmap if SHOW_BITMAP is true
  if (SHOW_BITMAP) {
    showBitmap();
  }

  // Default text settings
  display.cp437(true);  // Use correct CP437 character codes
  display.setTextSize(1);
  display.setTextColor(SSD1306_WHITE);
  display.clearDisplay();
}


// Function to show startup display
void showStart() {
  int16_t text_x, text_y;
  uint16_t text_w, text_h;

  // Clear display, set size
  display.clearDisplay();
  display.setTextSize(2);
  display.setTextColor(SSD1306_WHITE);

  // Calculate text bounds (0, 0 is a dummy position for now)
  display.getTextBounds(STARTUP_TEXT, 0, 0, &text_x, &text_y, &text_w, &text_h);

  // Calculate coordinates to center the text
  int16_t x = (SCREEN_WIDTH - text_w) / 2;
  int16_t y = (SCREEN_HEIGHT - text_h) / 2;

  display.setCursor(x, y);
  display.print(STARTUP_TEXT);
  display.display();
  delay(SCREEN_STARTUP_DISPLAY_TIME);
  display.clearDisplay();
}

// Function to show bitmap image
void showBitmap() {
  display.clearDisplay();
  display.drawBitmap(0, 0, bitmap_image, SCREEN_WIDTH, SCREEN_HEIGHT, SSD1306_WHITE);
  display.display();
  delay(SCREEN_STARTUP_DISPLAY_TIME);

  // Scroll right
  display.startscrollright(0x00, 0x0F);
  delay(SCREEN_STARTUP_DISPLAY_TIME);
  display.stopscroll();
  delay(100);
  display.clearDisplay();
}

// Function to display IP Info
void showIPInfo() {
  // Print IP info
  Serial.printf("SSID    : %s\n", WIFI_SSID);
  Serial.printf("HOSTNAME: %s\n", WiFi.getHostname());
  Serial.printf("IP      : %s\n", WiFi.localIP().toString().c_str());

  if (SHOW_IP_INFO) {
    display.clearDisplay();
    display.setCursor(0, 16);
    display.print("SSID: ");
    display.println(WIFI_SSID);
    display.setCursor(0, 26);
    display.print("Host: ");
    display.println(WiFi.getHostname());
    display.setCursor(0, 36);
    display.print("IP:   ");
    display.println(WiFi.localIP().toString().c_str());
    display.display();
  }
}

// Function to update the OLED with sensor readings
void updateOLED(float co2, float temperature, float temperatureF, float humidity) {
  // Clear Display
  display.clearDisplay();

  // IP Address
  display.setCursor(0, 0);
  display.print("IP: ");
  display.println(WiFi.localIP().toString().c_str());

  // Temperature
  display.setCursor(0, 16);
  display.print("Temp: ");
  display.print(temperatureF);
  display.print(" ");  // print space
  display.write(0xF8); // Print the degrees symbol
  display.println("F");

  // Humidity
  display.setCursor(0, 26);
  display.print("RH:   ");
  display.print(humidity);
  display.println(" %");

  // CO2
  display.setCursor(0, 36);
  display.print("CO2:  ");
  display.print(co2);
  display.println(" ppm");

  // Flower Mode
  display.setCursor(0, 56);
  display.print("Flower: ");
  if (FLOWER) {
    display.println("ON");
  } else {
    display.println("OFF");
  }

  // Update Display
  display.display();
}
// ============================================================================

// ============================================================================
// SETUP ----------------------------------------------------------------------
// ============================================================================
void setup() {
  pinMode(CO2_PIN, INPUT);                        // Set co2 pin mode
  pinMode(ROCKER_SWITCH_PIN, INPUT_PULLUP);       // Initialize digital input for the rocker switch
  dht.setup(DHT_PIN, DHTesp::DHT_MODEL_t::DHT22); // Initialize DHT sensor
  Serial.begin(BAUD_RATE);                        // Initialize Serial for debugging
  initOLED();                                     // Initialize OLED
  connectToWiFi();                                // Connect to Wi-Fi
  initSmartPlugs();                               // Initialize Smart Plugs

  // Define the root endpoint
  server.on(SERVER_PATH, HTTP_GET, [](AsyncWebServerRequest* request) {
    // Get sensor values
    float co2 = readCO2();
    float temperature = readTemperature();
    float temperatureF = celsiusToFahrenheit(temperature);
    float humidity = readHumidity();

    // Create a JSON document
    JsonDocument jsonDoc;

    // Add values to the JSON document
    jsonDoc["co2"]          = co2;
    jsonDoc["temperature"]  = temperature;
    jsonDoc["temperatureF"] = temperatureF;
    jsonDoc["humidity"]     = humidity;

    // Serialize JSON to string
    String jsonString;
    serializeJson(jsonDoc, jsonString);

    // Send the JSON response
    request->send(200, "application/json", jsonString);

  });
  // Start the server
  server.begin();
  Serial.println(F("Server started"));
}
// ============================================================================

// ============================================================================
// LOOP -----------------------------------------------------------------------
// ============================================================================
void loop() {
  static unsigned long lastUpdateTime = 0;
  static unsigned long lastWiFiCheck = 0;
  static unsigned long lastBitmapCheck = 0;
  static unsigned long lastPlugCheck = 0;
  unsigned long currentTime = millis();

  // Check position of flower switch
  updateFlowerState();

  // Update OLED display
  if (currentTime - lastUpdateTime >= SCREEN_UPDATE_TIME) {
    lastUpdateTime = currentTime;

    // Get sensor values
    float co2 = readCO2();
    float temperature = readTemperature();
    float temperatureF = celsiusToFahrenheit(temperature);
    float humidity = readHumidity();

    // Debug values
    Serial.printf("Temperature: %.2f C\n", temperature);
    Serial.printf("Temperature: %.2f F\n", temperatureF);
    Serial.printf("Humidity   : %.2f %%\n", humidity);
    Serial.printf("CO2        : %.2f ppm\n", co2);
    Serial.println(F("Updating display..."));

    // Update OLED display with latest sensor data
    updateOLED(co2, temperature, temperatureF, humidity);
  }

  // Periodically check Wi-Fi status
  if (currentTime - lastWiFiCheck >= WIFI_CHECK_INTERVAL) {
    lastWiFiCheck = currentTime;

    if (WiFi.status() != WL_CONNECTED) {
      Serial.println(F("Wi-Fi disconnected. Attempting to reconnect..."));
      WiFi.reconnect(); // Attempt to reconnect

      if (WiFi.status() != WL_CONNECTED) {
        Serial.println(F("Reconnection failed. Retrying full connection..."));
        connectToWiFi(); // Fallback to full connection
      } else {
        Serial.println(F("Reconnected to Wi-Fi."));
      }
    }
  }

  // Update Smart plugs
  if (currentTime - lastPlugCheck >= SMARTPLUG_UPDATE_TIME) {
    lastPlugCheck = currentTime;

    // Get sensor values
    float co2 = readCO2();
    float temperature = readTemperature();
    float temperatureF = celsiusToFahrenheit(temperature);
    float humidity = readHumidity();

    // Determine mode (Flower or Veg) and set desired values
    const char* mode = FLOWER ? "FLOWER" : "VEG";
    float desiredTemp = FLOWER ? DESIRED_TEMP_FLOWER : DESIRED_TEMP_VEG;
    float desiredHumidity = FLOWER ? DESIRED_HUMIDITY_FLOWER : DESIRED_HUMIDITY_VEG;

    // Handle temperature and humidity
    handleTemperature(temperatureF, desiredTemp, mode);
    handleHumidity(humidity, desiredHumidity, mode);
  }

  // Periodically show bitmap
  if (INTERRUPT_WITH_BITMAP) {
    if (currentTime - lastBitmapCheck >= INTERRUPT_BITMAP_TIME) {
      lastBitmapCheck = currentTime;
      showBitmap();
    }
  }
}
// ============================================================================
//vim: filetype=arduino:shiftwidth=2:softtabstop=2:expandtab:nowrap:cursorline:cursorcolumn:number:relativenumber

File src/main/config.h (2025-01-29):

/*
 * File: config.h
 *
 */

#pragma once

// ============================================================================
// CONFIGURATION --------------------------------------------------------------
// ============================================================================
// WIFI CONFIGURATION
constexpr char WIFI_SSID[]         = "";                 // Wi-Fi SSID
constexpr char WIFI_PASSWORD[]     = "";                 // Wi-Fi password
constexpr char WIFI_HOSTNAME[]     = "esp32-plant";      // Hostname
constexpr int  WIFI_TIMEOUT_TIME   = 30000;              // Timeout if unable to connect to WiFi (ms)
constexpr int  WIFI_CHECK_INTERVAL = 5000;               // Check WiFi time (ms)

// SERVER CONFIGURATION
constexpr uint16_t SERVER_PORT = 80;                     // Port for the web server
constexpr char     SERVER_PATH[] = "/";                  // Path for serving the data

// PINS CONFIGURATION
constexpr uint8_t CO2_PIN           = 35;                // Analog pin for CO2 sensor
constexpr uint8_t DHT_PIN           = 27;                // GPIO pin for DHT sensor
constexpr uint8_t ROCKER_SWITCH_PIN = 19;                // GPIO pin for flower rocker switch

// SCREEN CONFIGURATION
constexpr int     SCREEN_WIDTH                = 128;     // OLED display width, in pixels
constexpr int     SCREEN_HEIGHT               = 64;      // OLED display height, in pixels
constexpr uint8_t SCREEN_ADDRESS              = 0x3C;    // Address of OLED display (could also be '0x3D' depending on screen resolution)
constexpr int     SCREEN_UPDATE_TIME          = 1000;    // Time to wait before updating OLED (ms)
constexpr int     SCREEN_STARTUP_DISPLAY_TIME = 3000;    // Startup screen delay time (ms)
bool              SHOW_STARTUP                = true;    // Set to true to show the startup sequence
bool              SHOW_BITMAP                 = true;    // Set to true to show the bitmap
bool              SHOW_IP_INFO                = true;    // Set to true to show IP information
constexpr char    STARTUP_TEXT[]              = ":)";    // Startup custom text
bool              INTERRUPT_WITH_BITMAP       = true;    // Periodically show bitmap
constexpr int     INTERRUPT_BITMAP_TIME       = 300000;  // Check WiFi time (ms)

// SMART PLUG CONFIGURATION
const char      *intakePlugAlias        = "tent1_intake";     // Kasa plug alias (Intake)
const char      *exhaustPlugAlias       = "tent1_exhaust";    // Kasa plug aliases (Exhaust)
const char      *humidifierPlugAlias    = "tent1_humidifier"; // Kasa plug aliases (Humidifier)
constexpr int   SMARTPLUG_UPDATE_TIME   = 30000;              // Update smart plugs time (ms)
bool            FLOWER                  = false;              // Flower default value (this changes based on rocker switch)
constexpr float DESIRED_TEMP_VEG        = 80.0;               // Desired temperature in F (veg)
constexpr float DESIRED_HUMIDITY_VEG    = 50.0;               // Desired humidity in percentage (veg)
constexpr float DESIRED_CO2_VEG         = 800.0;              // Desired CO2 level (ppm) (veg)
constexpr float DESIRED_TEMP_FLOWER     = 70.0;               // Desired temperature in F (flower)
constexpr float DESIRED_HUMIDITY_FLOWER = 45.0;               // Desired humidity in percentage (flower)
constexpr float DESIRED_CO2_FLOWER      = 1000.0;             // Desired CO2 level (ppm) (flower)
constexpr float TEMP_HYSTERESIS         = 1.0;                // Temperature hysteresis to prevent rapid switching
constexpr float HUMIDITY_HYSTERESIS     = 5.0;                // Humidity hysteresis to prevent rapid switching
constexpr float CO2_HYSTERESIS          = 100.0;              // CO2 hysteresis to prevent rapid switching

// SERIAL CONFIGURATION
constexpr int BAUD_RATE = 115200;                        // Baud rate
// ============================================================================
//vim: filetype=arduino:shiftwidth=2:softtabstop=2:expandtab:nowrap:cursorline:cursorcolumn:number:relativenumber

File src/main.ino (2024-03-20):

#include "config.h"

#include "WiFi.h"
#include "ESPAsyncWebServer.h"
#include "DHTesp.h"

// Define the WiFi SSID (network name) for connection
const char* const wifi_ssid     = "YourWifiSSID";

// Define the WiFi password for connection
const char* const wifi_password = "YourWifiPassword";

// Define the analog pin for CO2 measurement
int analogPin = 35;

// Define the DHT sensor pin for temperature and humidity measurement
int dhtPin = 27;

// Initialize the DHT sensor object
DHTesp dht;

// Initialize the AsyncWebServer object on port 80
AsyncWebServer server(80);

// Function to get CO2 measurement
int getCo2Measurement() {

  // Read analog value from CO2 sensor
  int adcVal = analogRead(analogPin);

  // Calculate voltage based on ADC value
  float voltage = adcVal * (3.3 / 4095.0);

  // Check for zero voltage (sensor not operating correctly)
  if (voltage == 0)
  {
    return -1;
  }
  // Check for low voltage (sensor pre-heating)
  else if (voltage < 0.4)
  {
    return -2;
  }
  // Calculate CO2 measurement based on voltage difference
  else
  {
    float voltageDifference = voltage - 0.4;
    return (int) ((voltageDifference * 5000.0) / 1.6);
  }
}

void setup() {

  // Setup DHT sensor on specified pin
  // dht.setup(dhtPin);
  dht.setup(dhtPin, DHTesp::DHT_MODEL_t::DHT22);

  // Begin serial communication for debugging
  Serial.begin(115200);

  // Connect to WiFi network using specified credentials
  WiFi.begin(wifi_ssid, wifi_password);

  // Wait for WiFi connection
  while (WiFi.status() != WL_CONNECTED) {
    delay(1000);
    Serial.println("Connecting to WiFi..");
  }

  // Print local IP address once connected
  Serial.println(WiFi.localIP());

  // Handle CO2 measurement request
  server.on("/co2", HTTP_GET, [](AsyncWebServerRequest * request) {

    // Get CO2 measurement
    int measurement = getCo2Measurement();

    // Prepare response message based on measurement
    String message;
    if(measurement == -1){message = "Sensor is not operating correctly";}
    else if(measurement == -2){message = "Sensor is pre-heating";}
    else {message = String(measurement) + " ppm";}

    // Send response with HTTP status 200 (OK)
    request->send(200, "text/plain", message);

  });

  // Handle temperature measurement request
  server.on("/temperature", HTTP_GET, [](AsyncWebServerRequest * request) {

    // Get temperature from DHT sensor
    float temperature = dht.getTemperature();

    // Send temperature response with HTTP status 200 (OK)
    request->send(200, "text/plain", String(temperature) + " ºC");
  });

  // Handle humidity measurement request
  server.on("/humidity", HTTP_GET, [](AsyncWebServerRequest * request) {

    // Get humidity from DHT sensor
    float humidity = dht.getHumidity();

    // Send humidity response with HTTP status 200 (OK)
    request->send(200, "text/plain", String(humidity) + " %");
  });

  // Start the web server
  server.begin();
}

void loop() {}

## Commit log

2024-03-20 Added ino code for esp32
2024-03-20 Updated maiin with setting up specific DHT sensor model
2024-03-20 Added 3d print section and dir
2024-03-21 Added schematic and replaced circuit image
    [esp32-plant.fzz]
2024-03-21 improved code: Renamed variables using camelCase for consistency. Added constant keywords to constant variables. Moved the function prototypes before the setup function for better organization. Used 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
2024-03-21 improved code: moved the Serial.begin() call to the top of the setup() function for consistency and clarity. Simplified the response message generation for CO2 measurement using a ternary operator. C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
2024-03-21 changed the request handler to listen to the root path (/) instead of separate paths for temperature, humidity, and CO2 measurements. The getAllMeasurements function gathers all measurements (tempera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
2024-03-21 added a new function prototype void handleMeasurementsRequest(AsyncWebServerRequest *request); to handle the measurements request. The logic for handling the measurements request is moved to the hand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
2024-03-21 Added printing hostname and signal strength
2024-03-21 Updated README to remove other sensors
2024-03-21 Prevent continuous WiFi reconnection attempts in loop()
    [main.ino]
2024-03-21 updated img and schematic
    [esp32-plant.fzz]
2024-03-22 updated schematic
    [esp32-plant.fzz]
2024-03-22 Added 3d models
    [DHT22_bottom.stl, DHT22_top.stl, MQ2-Bottom-02.stl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]
2024-03-28 Added soil moisture sensor
2024-03-30 updated schematics
2024-12-19 Bump requests from 2.28.2 to 2.32.2 in /grafana/sensor_data_collector
    Bumps [requests](https://github.com/psf/requests) from 2.28.2 to 2.32.2.
    - [Release notes](https://github.com/psf/requests/releases)
    - [Changelog](https://github.com/psf/requests/blob/main/HISTORY.md)
    - [Commits](https://github.com/psf/requests/compare/v2.28.2...v2.32.2)
    ---
    updated-dependencies:
    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
2024-12-20 Made esp32 code return json. Updated python script
2025-01-14 Removed soil moisture sensor
2025-01-14 Removed soil moisture sensor from python file
2025-01-14 Removed soil moisture sensor pin
2025-01-15 Changed default esp32 url
2025-01-21 Set pin mode
2025-01-21 Added functions for reading sensors
2025-01-21 Made co2 sensor return 0 if error or preheating
2025-01-21 Changed from printing string to float
2025-01-22 Fixed string error. now checking length. Formatteed comments. wrapped in if
    [config.h]
2025-01-23 Added 30 pin pinout
2025-01-23 Added F() to println
2025-01-24 Fixed kasa object type errors
    [main.ino]
2025-01-24 display.cp437(true); // Use correct CP437 character codes
    [main.ino]
2025-01-24 Added different temp and humidity values for veg and flower
2025-01-24 Adjusted values for veg and flower
2025-01-26 Updated gitignore
    [ESP32-housing.FCStd]
2025-01-26 Added FreeCAD model. Updated gitignore
    [ESP32-housing.FCStd]
2025-01-26 Added bottom cut. Exported as STL and 3MF
    [ESP32-housing.3mf, ESP32-housing.FCStd, ESP32-housing.stl]
2025-01-26 Fixed humidity plug errors. Changed default settings
    [config.h, main.ino]
2025-01-27 Mad walls thicker. Made posts smaller
    [ESP32-housing.FCStd]
2025-01-27 Added champfers
    [ESP32-housing.3mf, ESP32-housing.FCStd, ESP32-housing.stl]
2025-01-27 Added rocker switch to set flower state
2025-01-27 Made oled display the current flower mode
2025-01-29 3d model
    [ESP32-housing.FCStd]
2025-01-29 Changed temp and switch pin
2025-01-29 Added new wiring image. updated readme
2025-02-11 Made exhaust fan turn on when humidity too high.
    [main.ino]
